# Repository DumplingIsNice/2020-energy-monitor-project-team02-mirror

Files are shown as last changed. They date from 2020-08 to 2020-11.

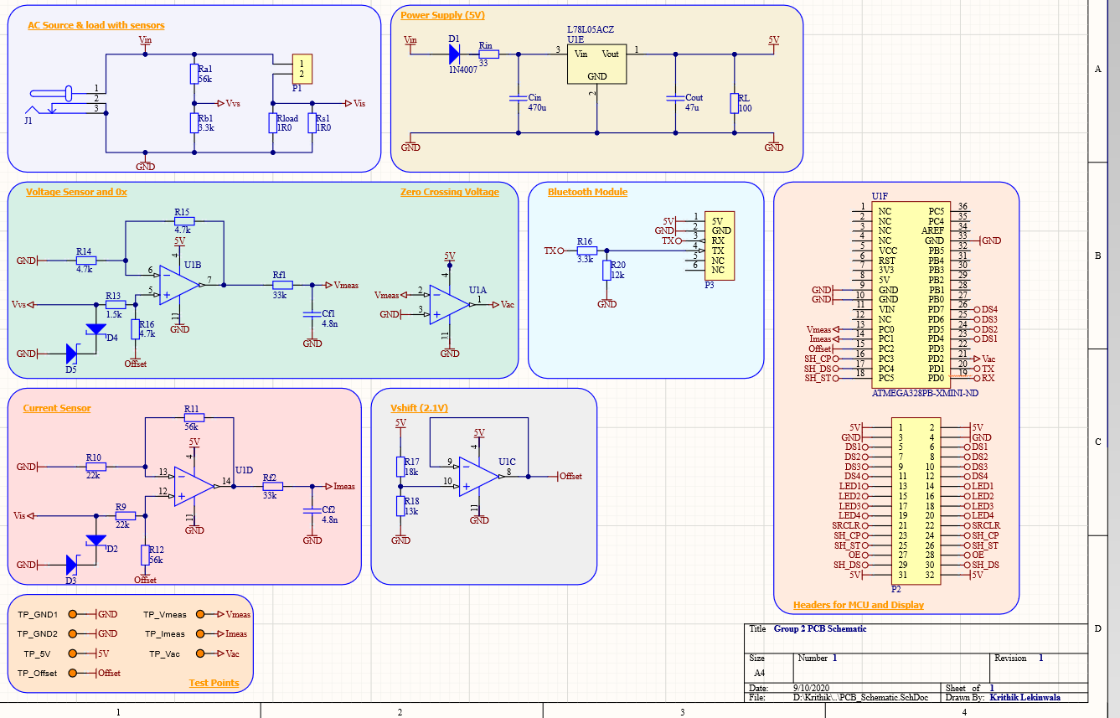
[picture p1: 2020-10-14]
PCB/PCB Schematic/PCBSchem.png

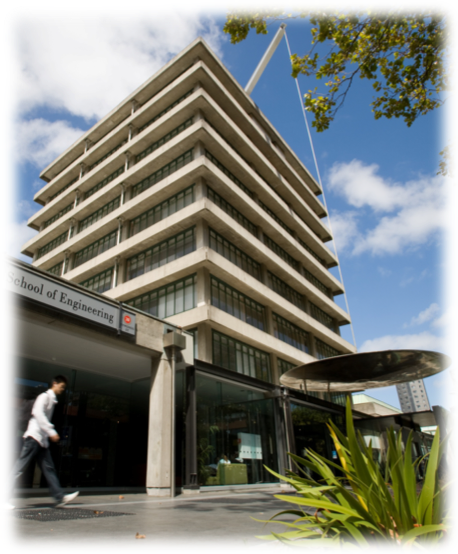
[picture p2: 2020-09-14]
Presentation/img/intro/UoAEng.png

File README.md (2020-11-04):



# Welcome to Team 02 EE209 Project Repository

- **Documentation:** Project brief, specifications and miscellaneous reminders.
- **Firmware:** Program for the ATmega328PB microcontroller.
- **Flowcharts:** Flowcharts of firmware structure.
- **Hardware:** Ltspice model.
- **PCB:** Altium schematic and PCB model.
- **Presentation:** Presentation slides and documents.
- **Proteus:** Proteus model of the energy monitor system.
- **Software:** Python implementation of a web application.

For details regarding each folder, please view the relevant README file.

For more detail regarding the project, please view the [Final Report](./EE209_Report.pdf).

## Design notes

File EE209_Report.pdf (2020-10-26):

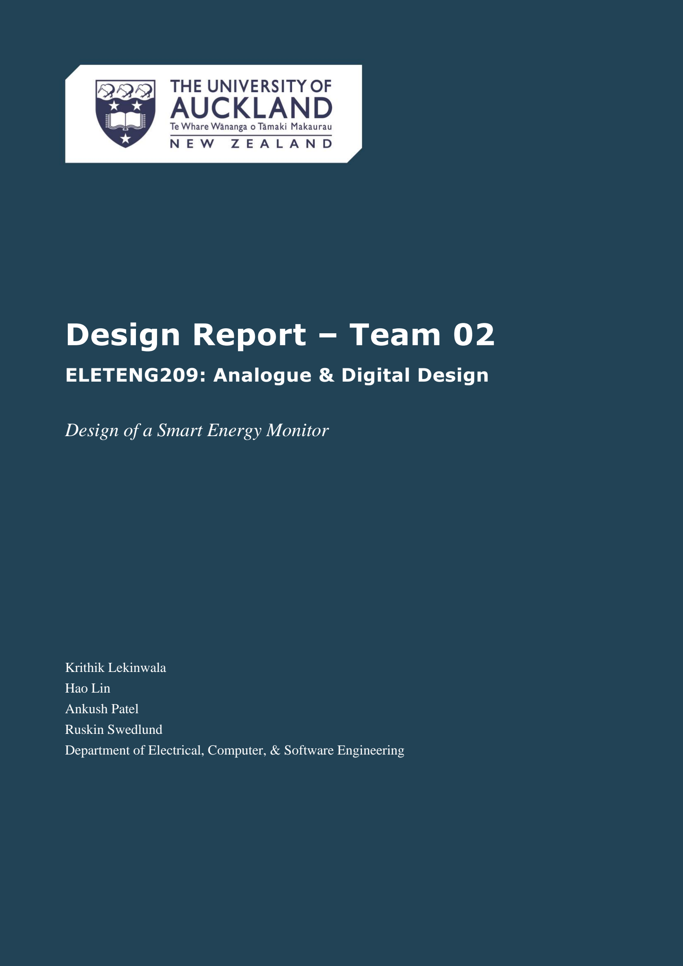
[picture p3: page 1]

# Design Report – Team 02

## ELETENG209: Analogue & Digital Design

## Design of a Smart Energy Monitor

Krithik Lekinwala
Hao Lin
Ankush Patel
Ruskin Swedlund
Department of Electrical, Computer, & Software Engineering

## Abstract

This report describes the design, validation, and operation of a smart energy monitor with the use of an

ATMega328PB capable of measuring the power utilised by an appliance using electrical hardware and

firmware implementations. Some key specifications provided with this Energy Monitor were accuracy,

exporting data to a remote website, and outputting measurements with Bluetooth and wired capability. The

maximum absolute error 5% with a typical error of 0.75%.

## Introduction

The main objective of this project was to gain valuable expertise and experience and to fulfil the course requirements of ELECTENG 209.

This Smart Energy Monitor can measure the power, peak current, RMS voltage, and total energy supplied to a load within specifications. The analogue circuitry measures, filters, and amplifies signals so they are appropriate digital processing. The microcontroller’s firmware samples these signals and interpolates the resulting data to provide an accurate digital representation of the analogue input signals. Results of the completed processing can be sent to a display, smartphones via Bluetooth, and computers using a USB to Serial cable. This overall architecture is summarised in Fig. 1.

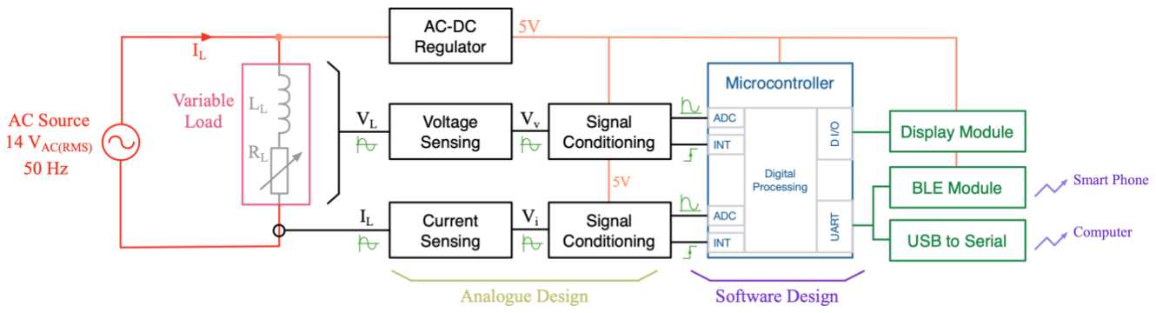
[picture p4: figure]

Fig. 1: A conceptual system diagram [1]

## Literature Research

Table I: A Comparison of existing energy meters

Parameter | Neurio Smart Monitor [2] | Efergy Pro [3]
Operating voltage range | 90 – 130V | 110-300V AC
Accuracy | ±1% of reading | 98%
Power Consumption | < 2 W | 0.2 W
Communication/Display Method | Wi-Fi, Bluetooth, wired | Wi-Fi
Peak Current | --- | 95 mA
Operating Temperature | 0 - 65°C | 0 - 35°C
Measurements | Irms, Vrms, W, X, Wh | W, Irms, Vrms, Energy (Wh)

## Design Specifications

The key differences are in the communication type, operating voltage, and types of measurements. The Neurio monitor measures all the quantities this monitor can, but in addition measures reactive power (X). Efergy Pro only measures Energy. [2] The Nuerio monitor provides Wi-Fi capability in addition to the methods used by the monitor described in this report. [3]
Table II: Design Specifications
Parameter | Configuration
Source Voltage | 14VRMS ± 10%
Source Frequency | 50Hz ± 2%
Load Range | 2.5VA to 7.5VA
Load Power Factor | 0.75 to 0.99
Measurement Accuracy | 5% of full-scale reading
ADC Conversion Rate | 1kHz or slower
LCD Display Information | Voltage, current, power and energy
LCD Display Units | VRMS, Apk, W and Wmin
LCD Scroll Rate | 1s
UART Baud Rate | 9600 Baud
Information Transferred Via UART | Voltage, Current, Power and Energy
PCB Size | 200 mm²
PCB Technology | Double layer with PTH
Device Technology | TH or SMT

## The Analogue Design

## The Schematic

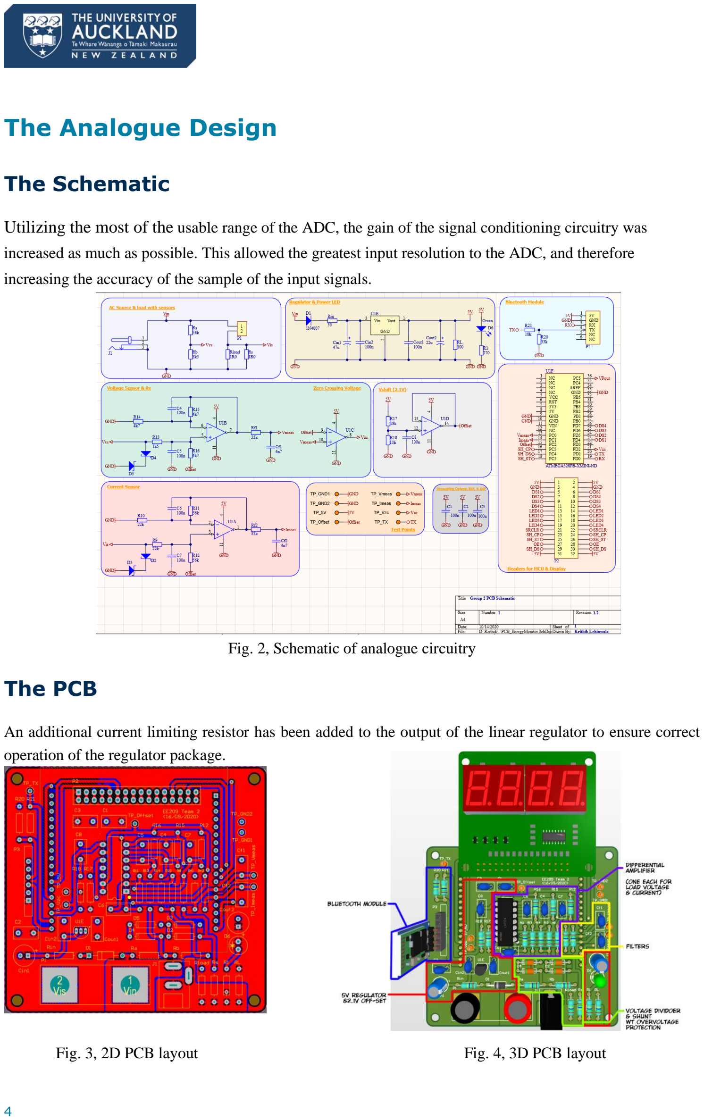
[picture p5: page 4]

Utilizing the most of the usable range of the ADC, the gain of the signal conditioning circuitry was

increased as much as possible. This allowed the greatest input resolution to the ADC, and therefore

increasing the accuracy of the sample of the input signals.

Fig. 2, Schematic of analogue circuitry

## The PCB

An additional current limiting resistor has been added to the output of the linear regulator to ensure correct operation of the regulator package.

Fig. 3, 2D PCB layout | Fig. 4, 3D PCB layout

## Design Validation

For naming convention refer to: https://ee2092020class.github.io/presentations/DigitalL4/presentation.html#5.

Table III: Key design parameters

Parameter | Calculated | Simulated
Gvs | (3300/56000 + 3300) = 0.056
Vvs when VAC is 15.4 Vrms | 0.989 V | 986 mV
Vvs when VAC is 12.6 Vrms | 0.81 V | 805 mV
Gis | 0.56
Vis when IAC is 0.60 Arms | 0.47 V | 0.446 V
Vis when IAC is 0.16 Arms | 0.127 V | 0.125 V
Gvo | (4700/4700) = 1
Vvo when VAC is 15.4 Vrms | 3.09 V | 3.09 V
Vvo when VAC is 12.6 Vrms | 2.91 V | 2.91 V
Gio | (56000/22000) = 2.55
Vio when IAC is 0.60 Arms | 3.1 V | 3.08 V
Vio when IAC is 0.16 Arms | 2.37 V | 2.37 V
Gvf | 1
Vvf when VAC is 15.4 Vrms | 3.32 V | 3.29 V
Vvf when VAC is 12.6 Vrms | 3.1 V | 3.08 V
Gif | 1
Vif when IAC is 0.60 Arms | 3.31 V | 3.29 V
Vif when IAC is 0.16 Arms | 2.42 V | 2.43 V
ΔVin of 5V regulator | 2.13 V | 1.56 V
ΔV5V of 5V regulator | 0 V | 0 V

## The Embedded Software Design

## Flowchart

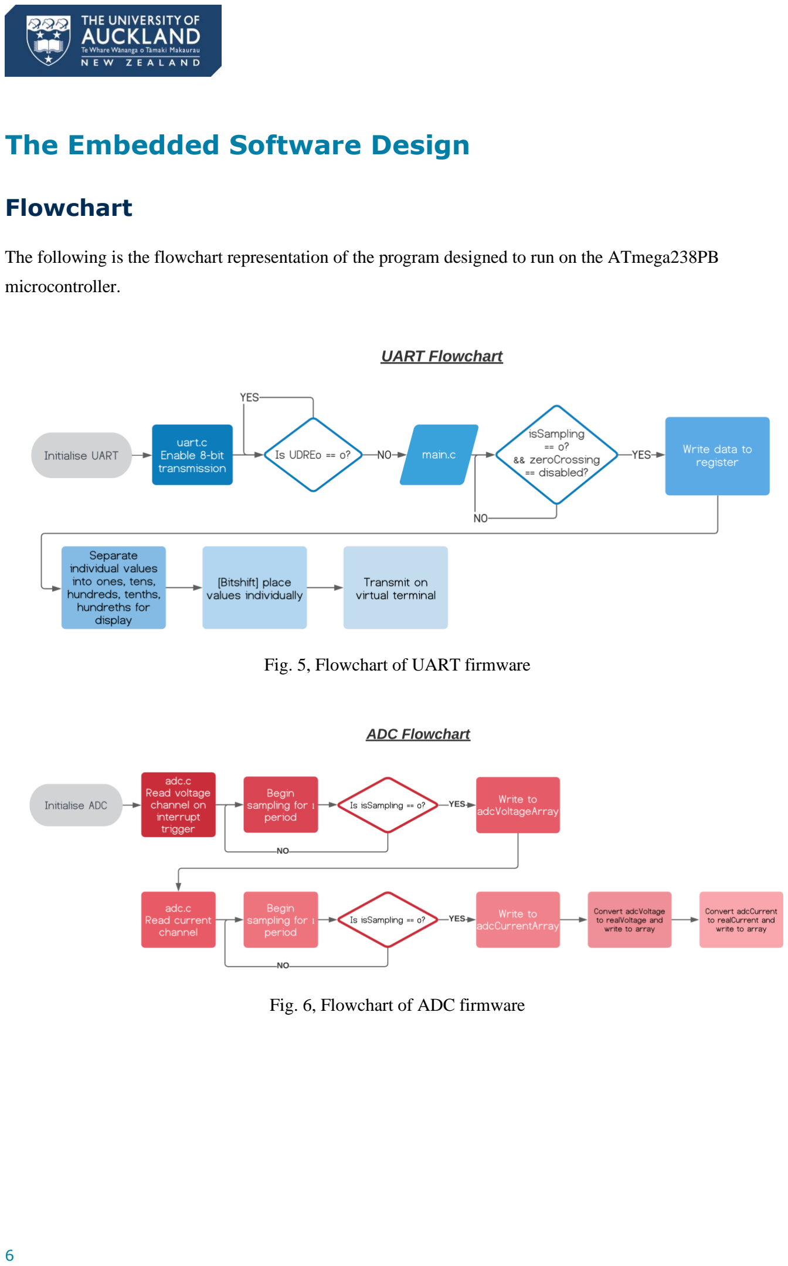
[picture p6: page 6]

The following is the flowchart representation of the program designed to run on the ATmega238PB

microcontroller.

Fig. 5, Flowchart of UART firmware

Fig. 6, Flowchart of ADC firmware

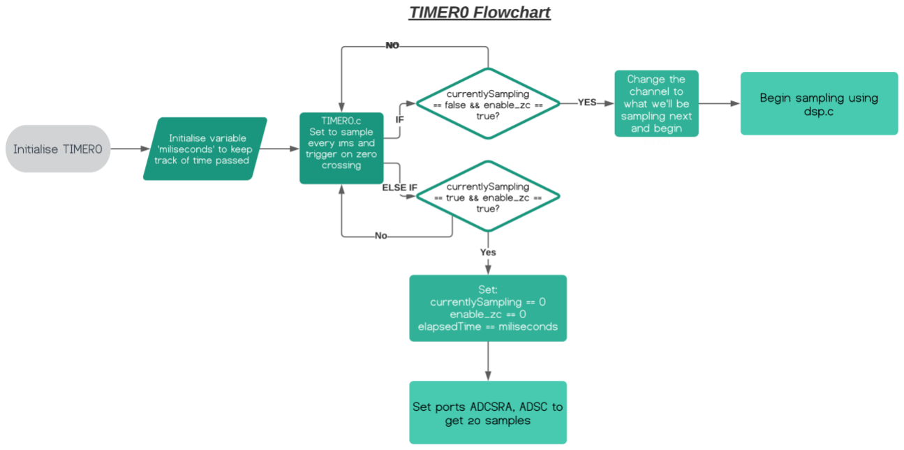
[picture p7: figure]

Fig. 6, Flowchart of TIMER0 firmware

In processing the samples, cubic interpolation and Simpsons rule was used to integrate points for power and RMS voltage. The cubic interpolation used was specifically chosen as the most suitable numerical integration method to accurately predict the peak values of imperfect sinusoidal waves.

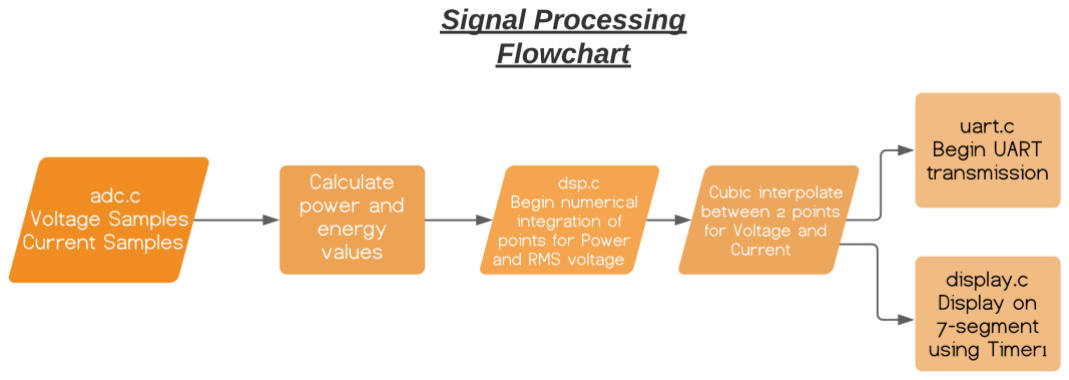
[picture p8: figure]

Fig. 7, Flowchart of digital signal processing firmware

## Custom Print Function

A custom print function was implemented for use by the UART peripheral to reduce clutter, memory used, and to increase functionality. This function can transmit directly to the terminal by using:

print(“xyz: %d %f”, current, voltage)

## Smart Energy Challenge

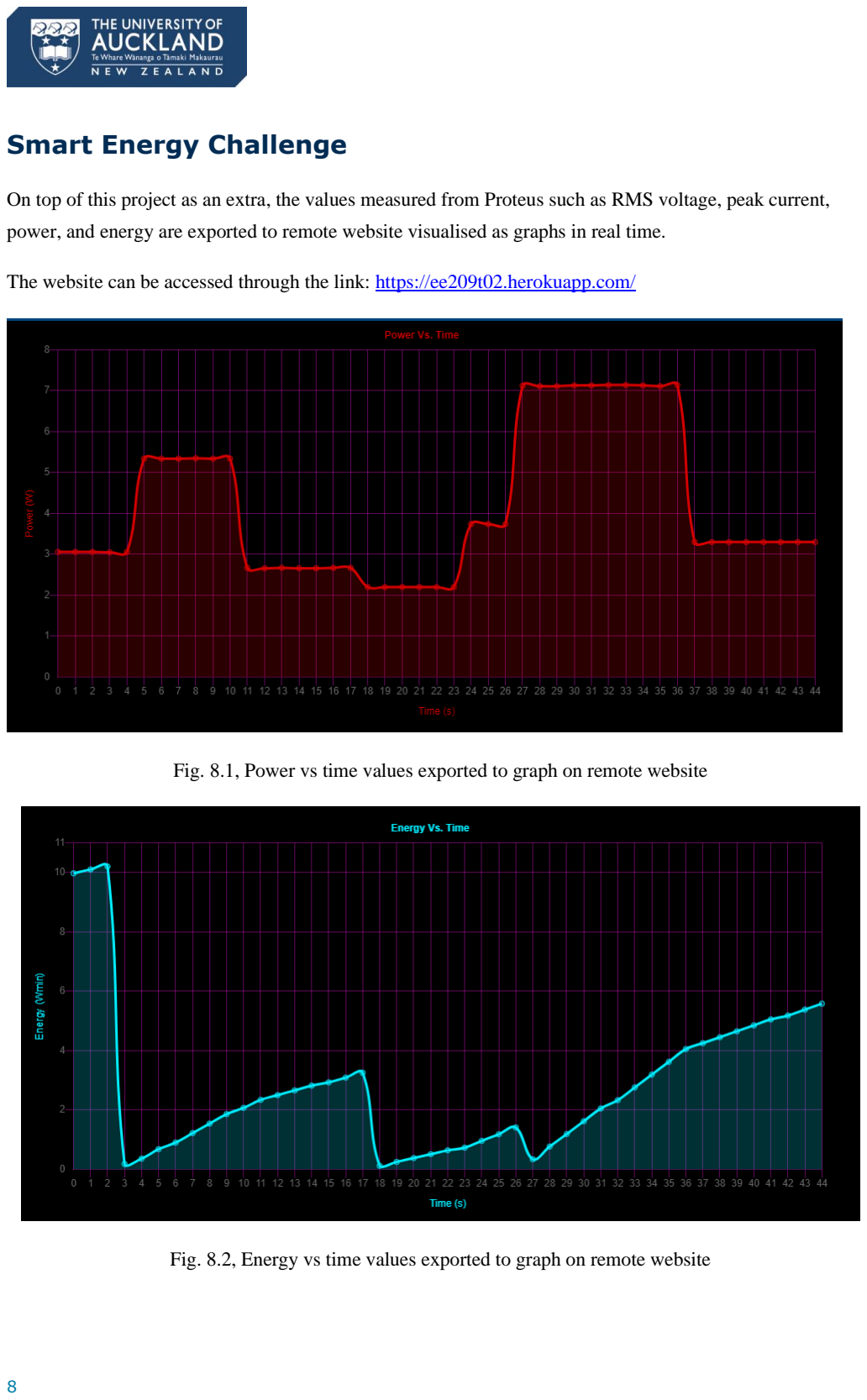
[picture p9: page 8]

On top of this project as an extra, the values measured from Proteus such as RMS voltage, peak current,

power, and energy are exported to remote website visualised as graphs in real time.

The website can be accessed through the link: https://ee209t02.herokuapp.com/

Fig. 8.1, Power vs time values exported to graph on remote website

Fig. 8.2, Energy vs time values exported to graph on remote website

## Peripheral Configurations

Table IV: UART configuration

Parameter | Configuration
Number of data bits | 8
Number of stop bits | 1
Baud rate | 9600
Parity mode | None
Transmission mode | Simplex (transmit)
Transmit mode | Polling (UDRE0)
Transmit voltage | 5 V

Table V: ADC configuration

Parameter | Configuration
Prescaler | 4 (sim), 128 (hardware)
Timer0 ADC mode | CTC A auto trigger
ADC interrupt time | 1ms
Voltage reading | ADC channel 0
Current reading | ADC channel 1
OCR0A | 99 (sim), 124 (hardware)

Table VI: Display Configuration

Parameter | Configuration
7-Segment pin operation | Common Cathode
Units display | Ds4
Clock Pulse bit | SH_CP
Timer2 interrupt time | 1ms
Timer2 OCR2A | 99 (sim), 124 (hardware)
Timer2 display update interval | 10ms
4 Display operation | Shift Register

Table VII: I/O pins

Parameter | Configuration
7 Seg Display Output | Ds1, Ds2, Ds3, Ds4 (PD4, PD5, PD6, PD7)
Reading Shift Register | SH_DS (PC4)
Toggle shift register | SH_ST (PC5)
LED toggle for testing operation | LED (PB5)

## Design Validation

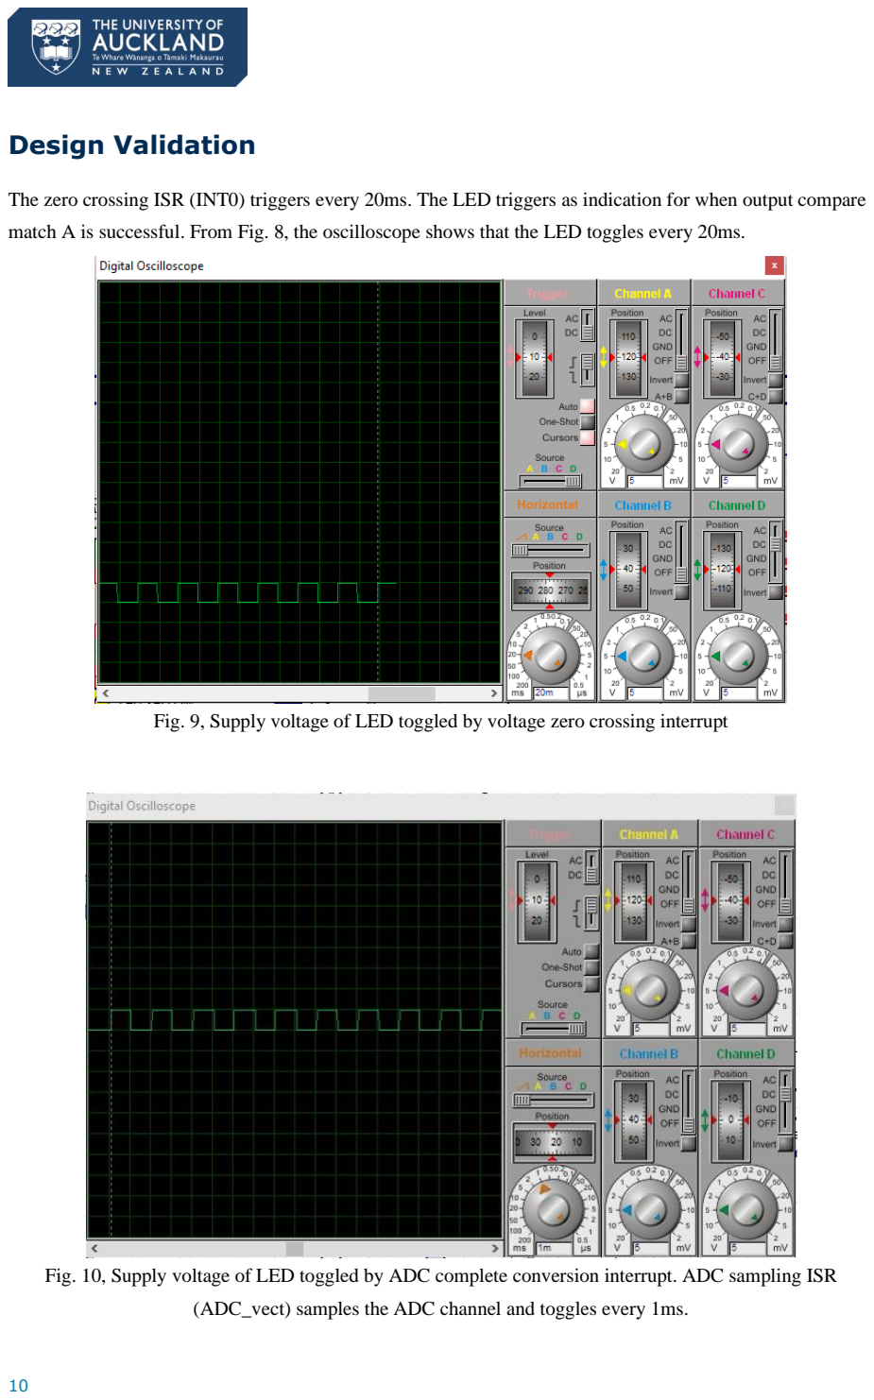
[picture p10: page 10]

The zero crossing ISR (INT0) triggers every 20ms. The LED triggers as indication for when output compare

match A is successful. From Fig. 8, the oscilloscope shows that the LED toggles every 20ms.

Fig. 9, Supply voltage of LED toggled by voltage zero crossing interrupt

Fig. 10, Supply voltage of LED toggled by ADC complete conversion interrupt. ADC sampling ISR

(ADC_vect) samples the ADC channel and toggles every 1ms.

Timer2 triggers approximately every 10.8ms. Timer2 is used to drive the refresh rate of the seven-segment

display. Shown in Fig 10, the shift register clock pulse control signal (SH_CP, in yellow) is used to move

data into the shift register.

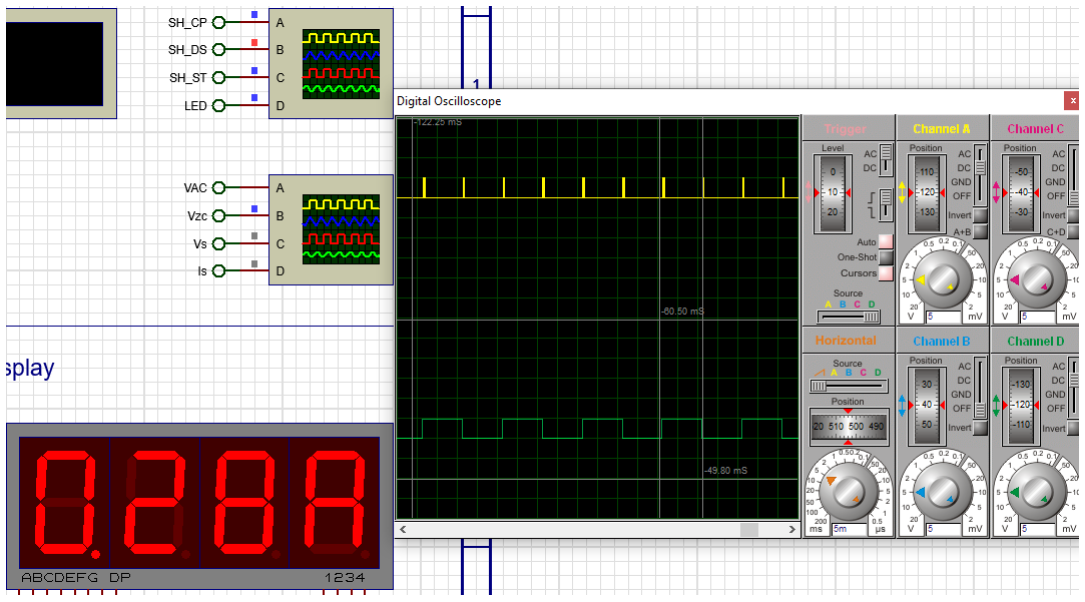
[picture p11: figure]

Fig. 11, Voltage supply to LED toggled by TIMER2 interrupt in green, shift register clock pulse in yellow

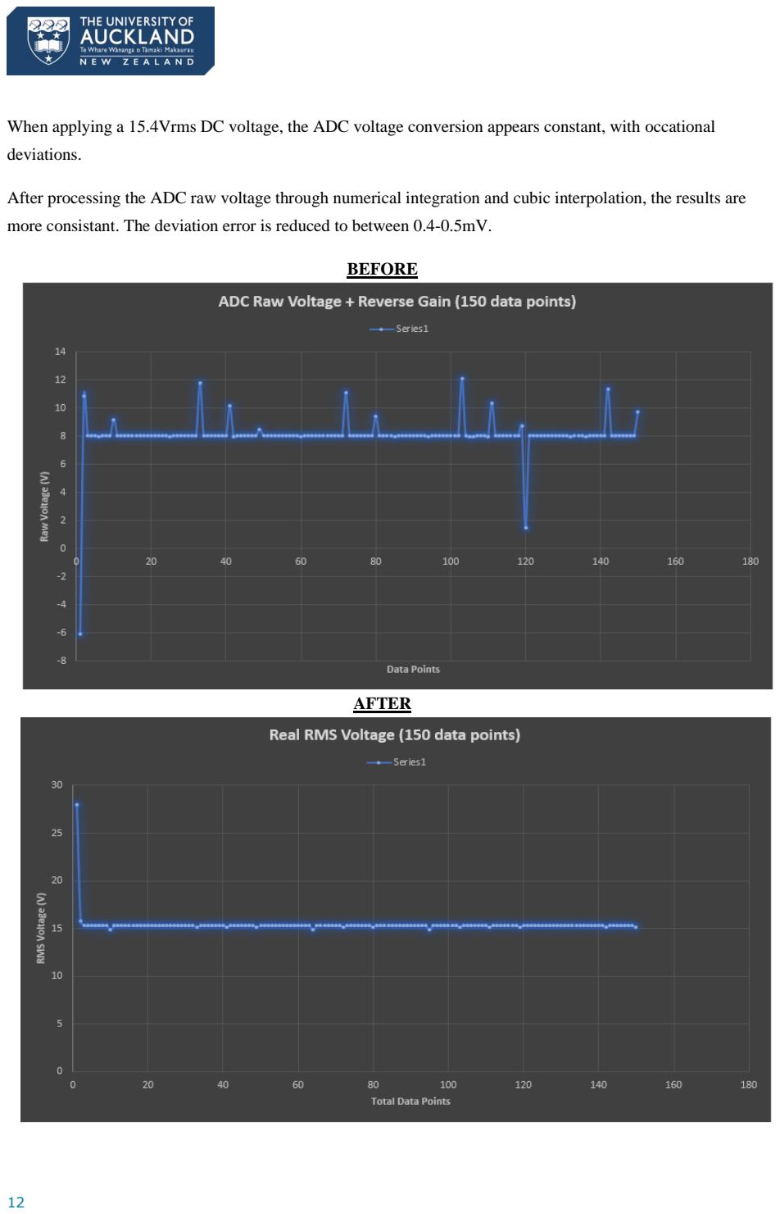
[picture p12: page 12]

When applying a 15.4Vrms DC voltage, the ADC voltage conversion appears constant, with occational

deviations.

After processing the ADC raw voltage through numerical integration and cubic interpolation, the results are

more consistant. The deviation error is reduced to between 0.4-0.5mV.

BEFORE

AFTER

## Performance of the Energy Monitor

## Design Validation

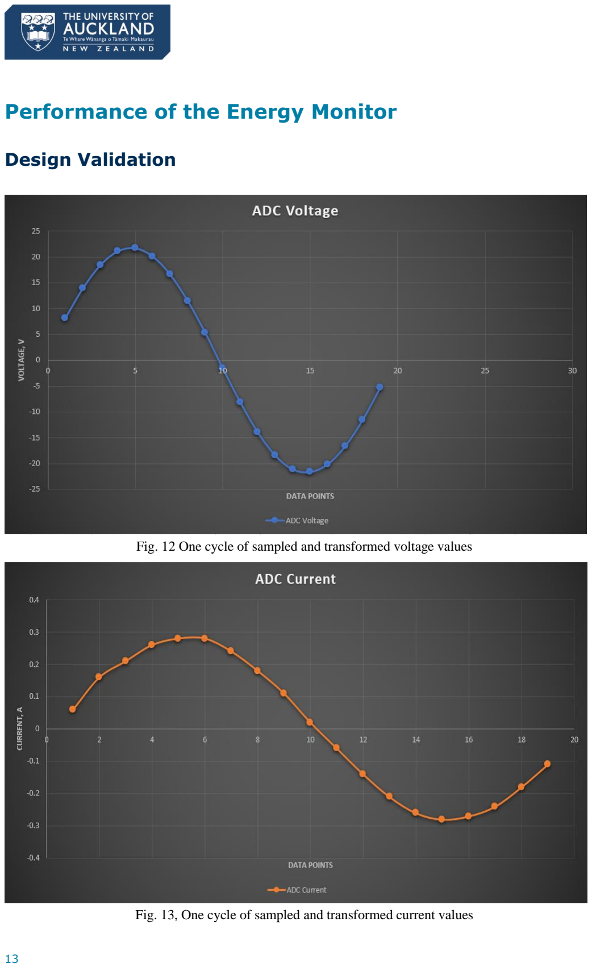
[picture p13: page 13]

Fig. 12 One cycle of sampled and transformed voltage values

Fig. 13, One cycle of sampled and transformed current values

## The Accuracy

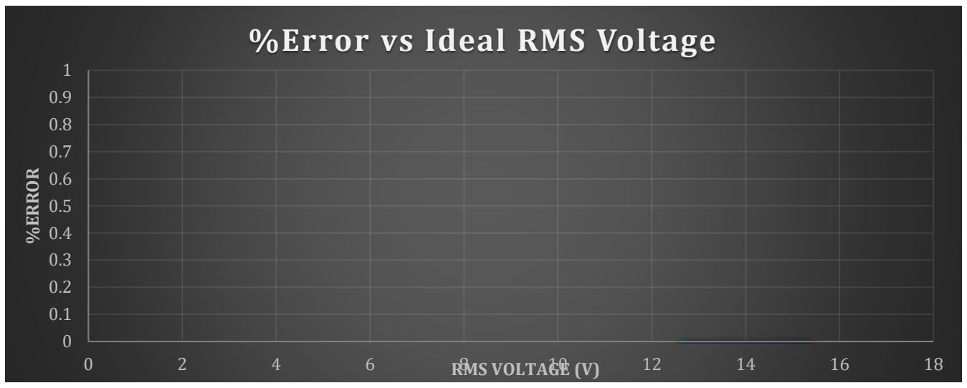
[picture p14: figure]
%ERROR; RMS VOLTAGE (V); %Error vs Ideal RMS Voltage

Fig. 14, Ideal Peak Current vs Error graph (most points not visible due to error being 0)

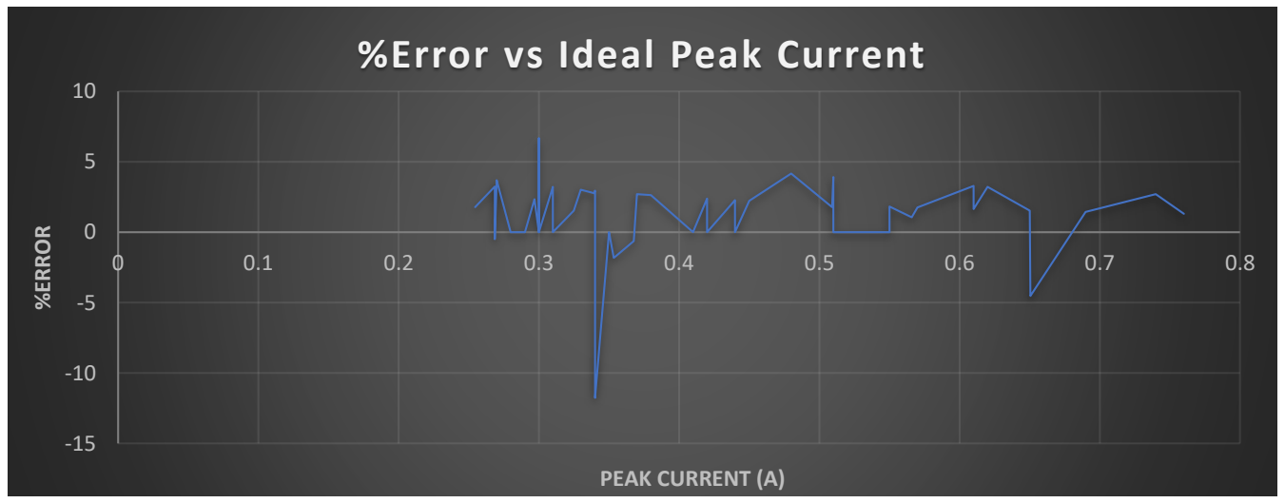
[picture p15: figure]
%ERROR; PEAK CURRENT (A); %Error vs Ideal Peak Current

Fig. 15, Ideal RMS Voltage vs Error graph

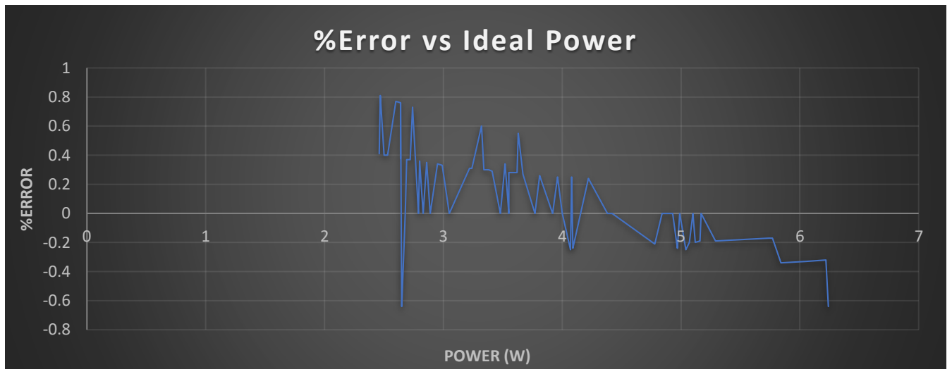
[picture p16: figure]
%ERROR; POWER (W); %Error vs Ideal Power

Fig. 16, Ideal Average Power vs Error graph

## Conclusions

In conclusion to this Energy Monitor Project, this report discusses how the Energy Monitor operates in terms

of its firmware and hardware, accuracy, workability, and comparisons to commercial grade products. The

typical accuracy reached using numerical and cubic interpolation techniques was approximately 0.75%. The

aim of this report was to give the reader some insight on an Energy Monitor and how it can be used in a real-

world application example.

## References

[1] D. J. Thrimawithana, Class Lecture, Topic: "Analogue & Embedded Software Design: An Introduction to the Course" ELECTENG 209, Department of Electrical, Computer, and Software Engineering, The University of Auckland, Auckland, October 2020.
[2] Efergy Pro Energy Monitor, https://efergy.com/efergy-pro-specs/#
[3] Neurio Home Energy Monitor Datasheet, https://www.neur.io/wp-content/uploads/Neurio_Home_Energy_Monitoring_Kit_SpecSheet.pdf (https://www.neur.io/wp-content/uploads/Neurio_Home_Energy_Monitoring_Kit_SpecSheet.pdf)

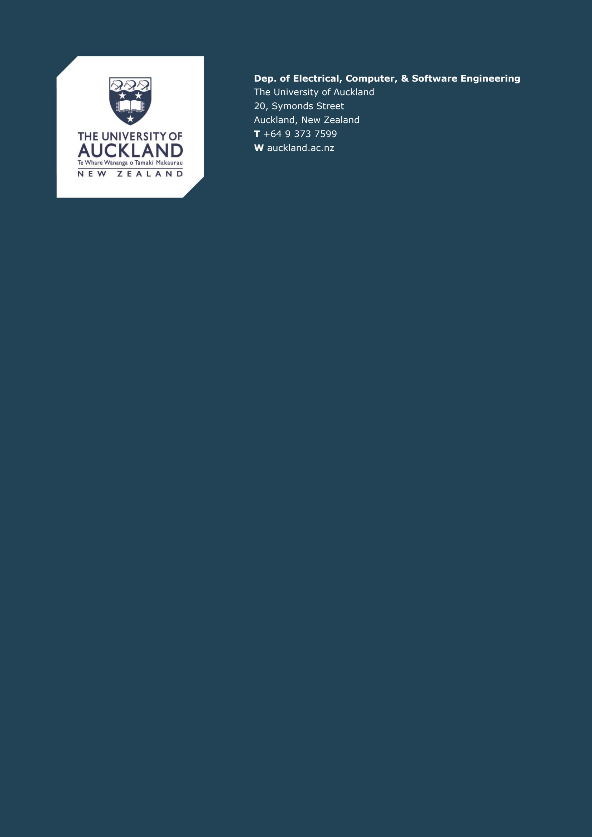
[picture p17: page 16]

Dep. of Electrical, Computer, & Software Engineering The University of Auckland
20, Symonds Street
Auckland, New Zealand
T +64 9 373 7599
W auckland.ac.nz

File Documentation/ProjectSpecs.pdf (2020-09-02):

## ENGGEN209 - Team 2 - Project Specifications:

Overview Of System To Impliment:

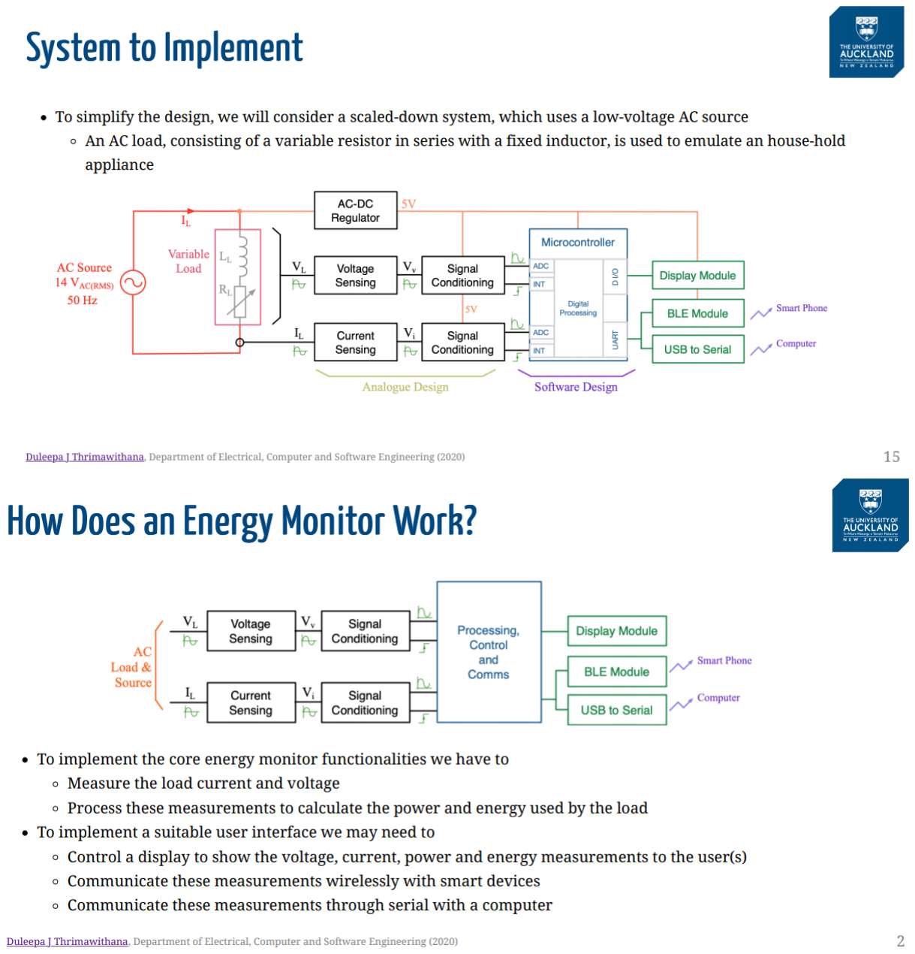
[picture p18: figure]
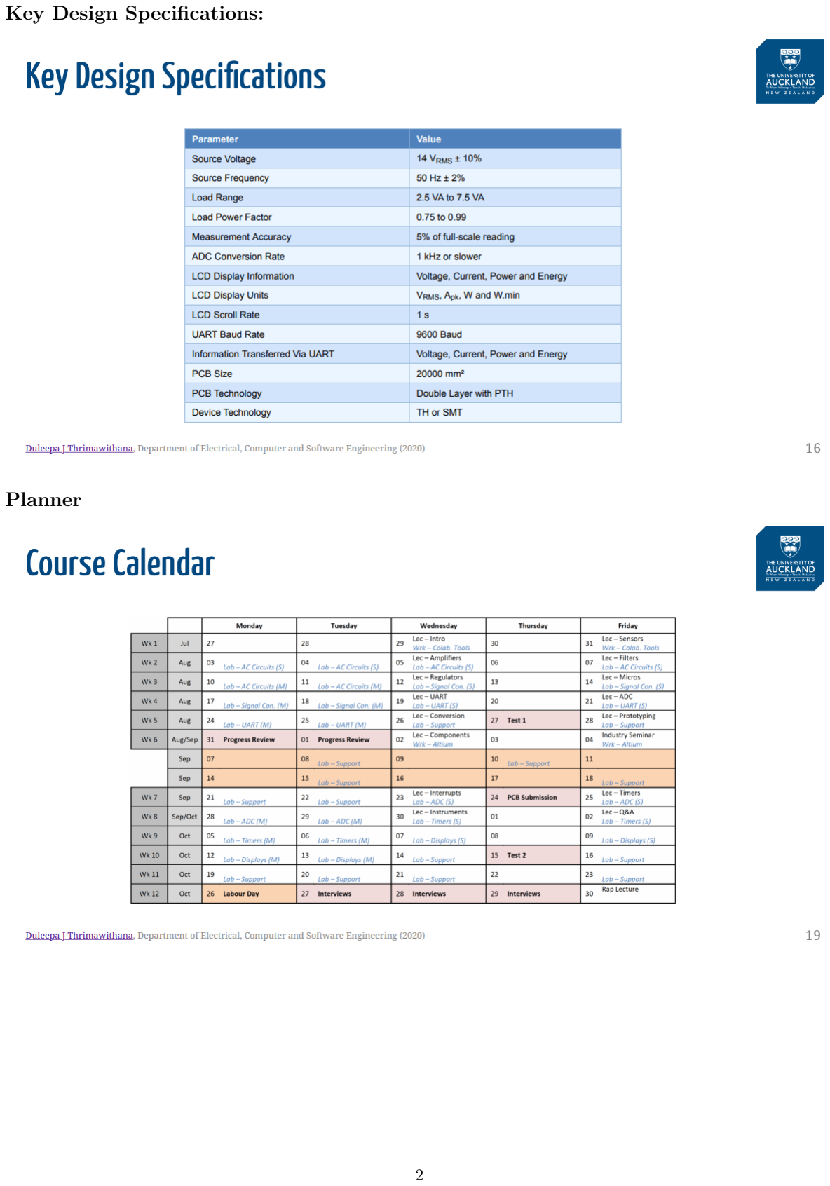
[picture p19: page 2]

Key Design Specifications:

Planner

Circuitry to sense the voltage and current supplied to the load:

- Signal conditioning circuitry to amplify and filter the sensed voltage and current signals.
- A software-based digital processing system, which uses an ATmega328P microcontroller, to convert the analogue signals provided by the signal conditioning circuit to digital form and calculate the voltage, current, power and energy.
- AC to DC regulator circuitry to generate a 5 V DC supply for the analogue (and digital) circuitry employed in the energy monitor.
- A 7-segment LCD display module, which is connected to the microcontroller via a shift-register, to show the calculated information.
- A Bluetooth LE module, which is connected to the microcontroller via Universal Asynchronous Receiver/Transmitter (UART), to communicate information with a smart device like a phone.
- A USB interface with serial emulation, which is connected to the microcontroller via UART, to communicate information with a laptop/PC.

Provided Items

- The source configuration circuit.
- An Xplained Mini 328PB microcontroller module with headers providing easy access to the ports
- An HM-10 Bluetooth LE module which contains a CC2540 system-on-chip (SoC) and associated circuitry needed to interface directly with the UART port of the microcontroller
- A 4-digit seven-segment LCD display module which contains a 74HC595 shift-register and the logic circuitry required to interface with digital IO pins of the microcontroller.

Bluetooth Module UART Specs:

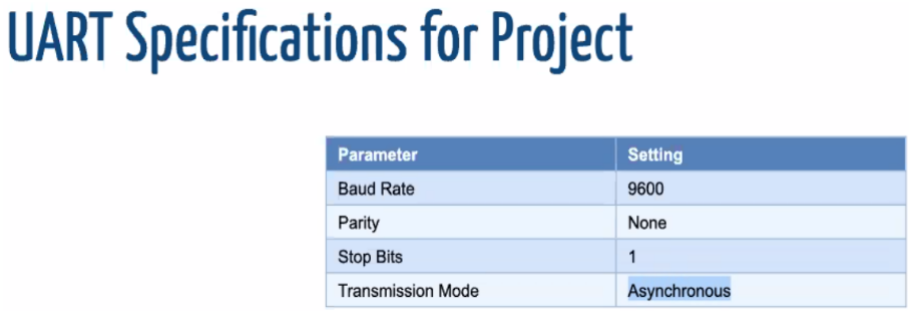
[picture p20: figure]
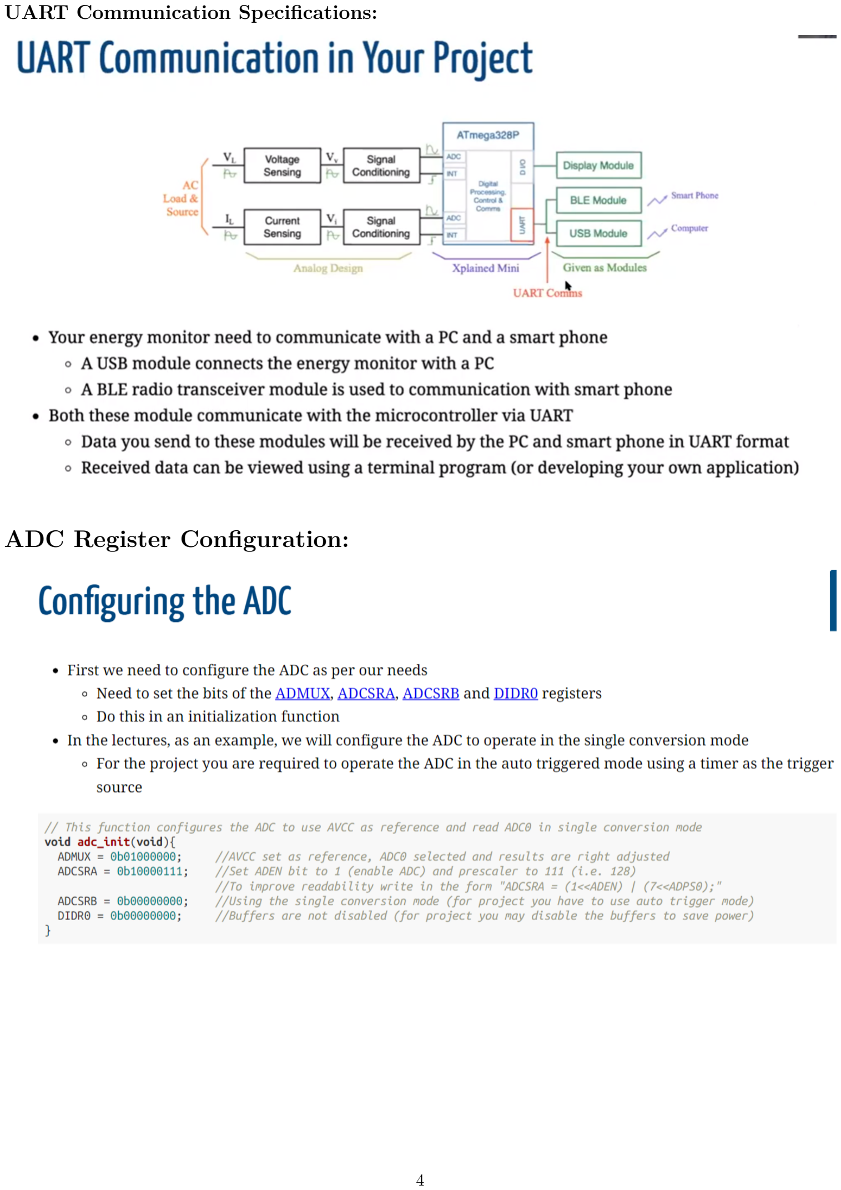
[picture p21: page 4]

UART Communication Specifications:

## ADC Register Configuration:

## PCB Design Considerations:

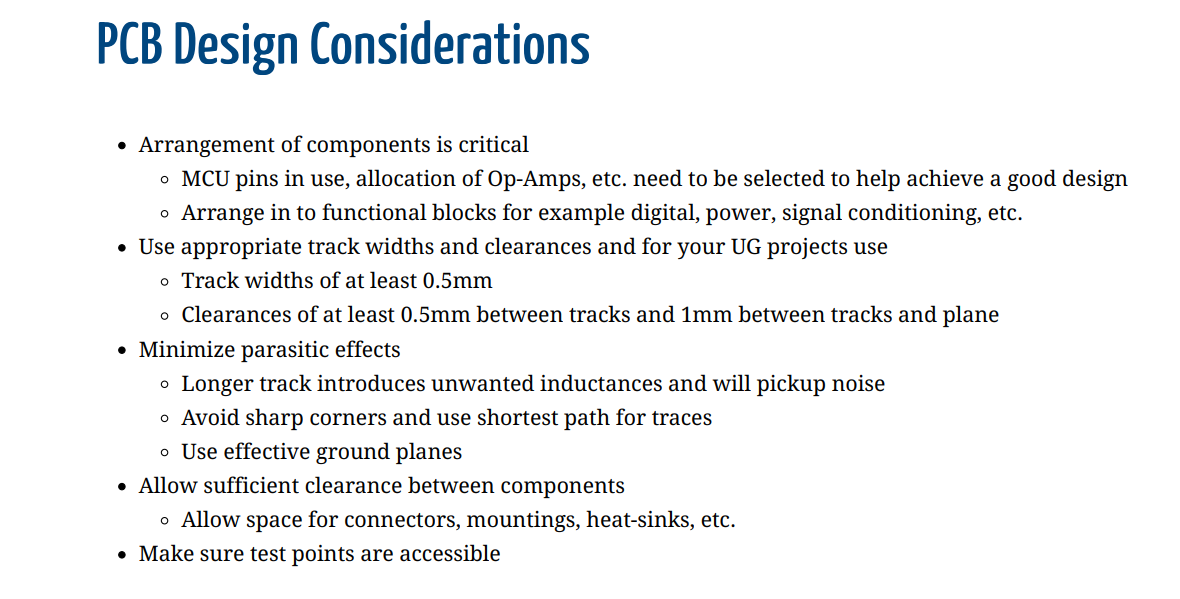
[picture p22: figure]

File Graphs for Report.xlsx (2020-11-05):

Voltage | Current
8.15 | 0.06
13.9 | 0.16
18.4 | 0.21
21.1 | 0.26
21.7 | 0.28
20.1 | 0.28
16.6 | 0.24
11.5 | 0.18
5.34 | 0.11
-1.49 | 0.02
-8.07 | -0.06
-13.9 | -0.14
-18.4 | -0.21
-21.1 | -0.26
-21.6 | -0.28
-20.1 | -0.27
-16.6 | -0.24
-11.5 | -0.18
-5.27 | -0.11
15.4 |  | Error | 0.2
RMS Voltage | Ideal RMS Voltage |  | Peak Current | Ideal Peak Current x (√2) | Error | Average Power | Ideal Average Power | Error | Ideal Vrms | %Error | Ideal Cpk |  | %Error | Ideal P |  | %Error
15.8 | 15.4 | 0.4 | 0.28 | 0.2828427125 | 0.002842712475 | 3.01 | 3.08 | 0.07 | 12.6 | 0 | 0.254558 | 1.790554608 | 1.79 | 2.46 | 0.406504065 | 0.41
15.3 | 15.4 | 0.1 | 0.28 | 0.2828427125 | 0.002842712475 | 3.06 | 3.08 | 0.02 | 12.6 | 0 | 0.2687 | 3.237811686 | 3.24 | 2.47 | 0.8097165992 | 0.81
15.3 | 15.4 | 0.1 | 0.28 | 0.2828427125 | 0.002842712475 | 3.05 | 3.08 | 0.03 | 12.7 | 0 | 0.2687 | -0.4838109416 | -0.48 | 2.5 | 0.4 | 0.4
15.3 | 15.4 | 0.1 | 0.28 | 0.2828427125 | 0.002842712475 | 3.05 | 3.08 | 0.03 | 12.8 | 0 | 0.27 | 3.703703704 | 3.7 | 2.53 | 0.395256917 | 0.4
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

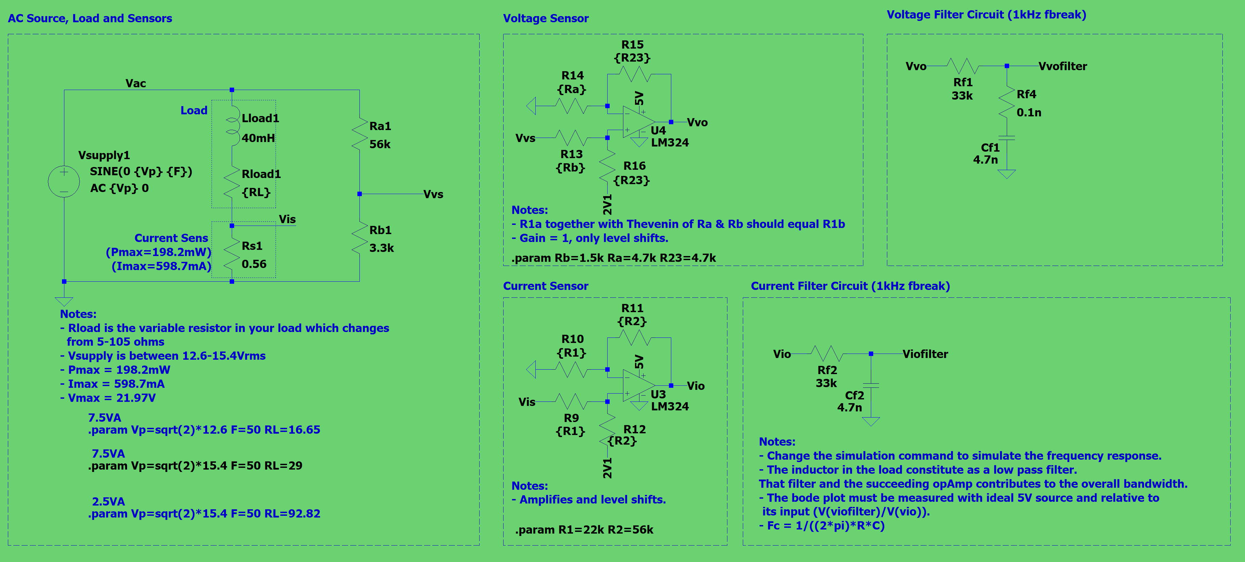
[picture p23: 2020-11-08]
Presentation/img/Ltspice Schematic.png

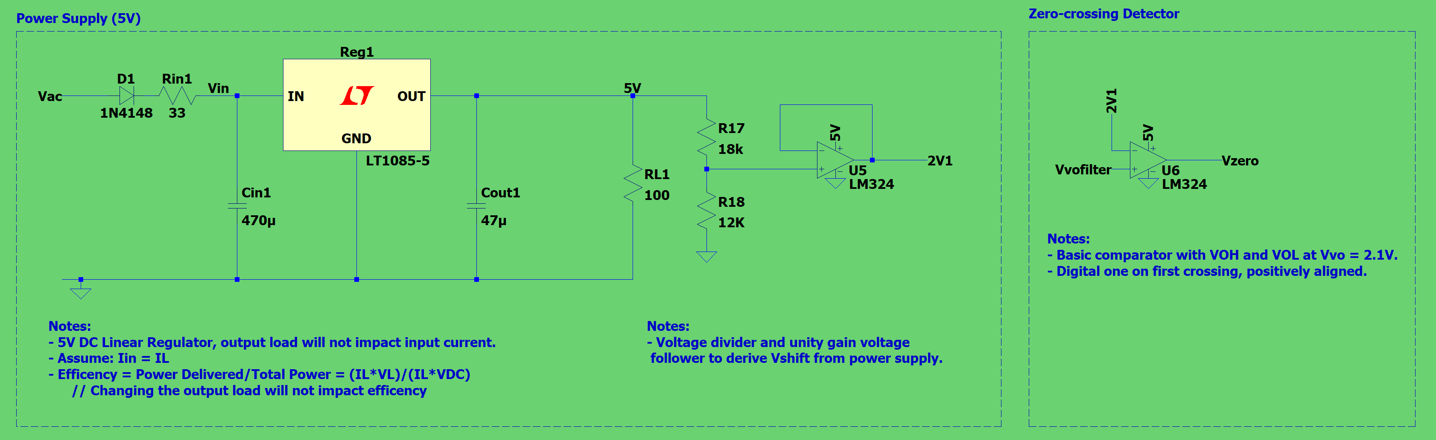
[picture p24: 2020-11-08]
Presentation/img/Ltspice Schematic2.png

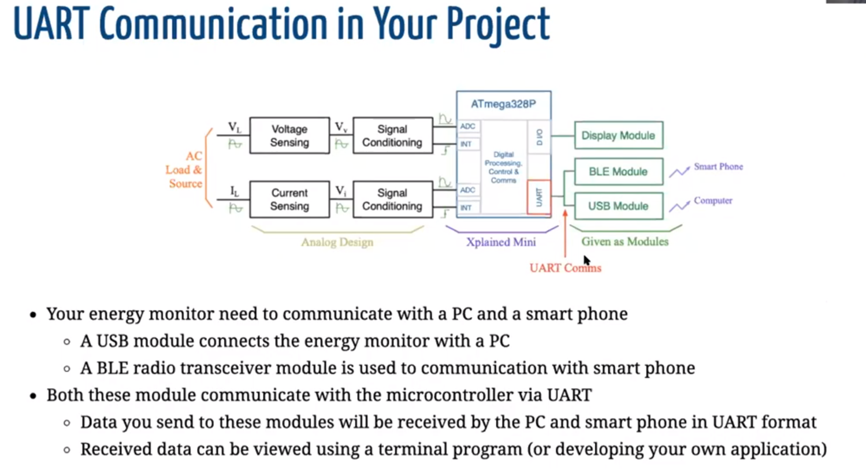
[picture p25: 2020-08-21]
Documentation/src/project_specs/UARTCommunication.png

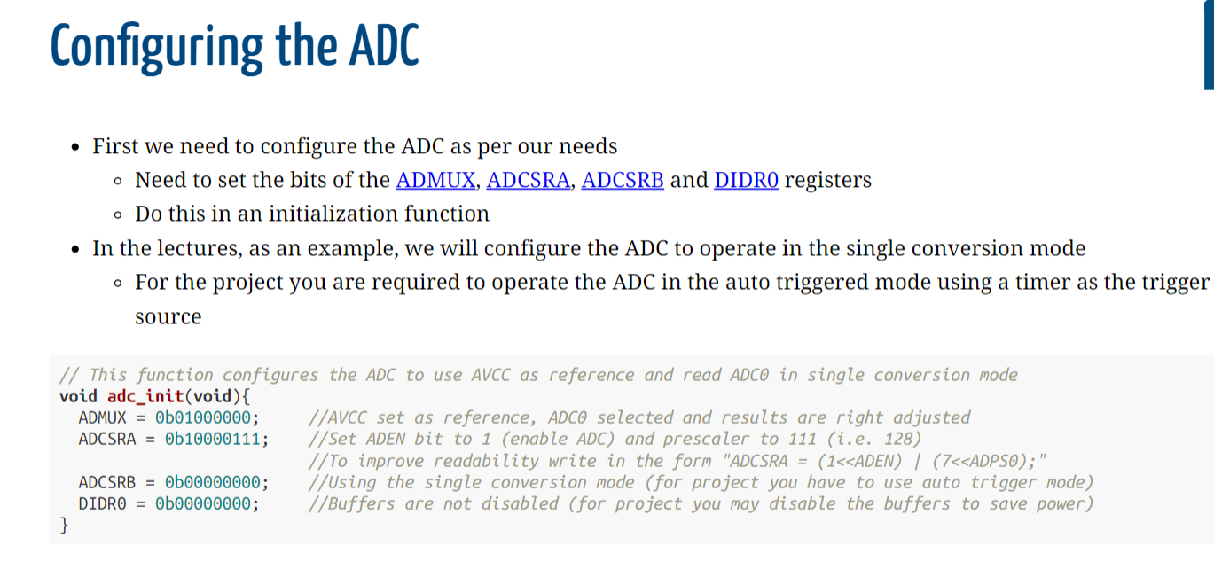
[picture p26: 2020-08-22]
Documentation/src/project_specs/ADCConfig.png

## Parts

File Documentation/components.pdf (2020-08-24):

# ELECTENG209 Team 02: Project Component Values

### Ankush Patel, Daniel Lin, Krithik Lekinwala, Rukin Swedlund

13/08/2020

1

## Contents

1 Introduction | 3
2 Voltage & Current Sensors | 4
3 Measurement Conditioning | 6
4 Filters | 8
5 Zero Crossing Detection | 8
6 The E-12 Series: | 9

2

## 1 Introduction

This document details the circuits and component values we will use to build our project. The structure and order of the component values and circuits described follow the order of the Labs.
The basic structure of components is as follows:

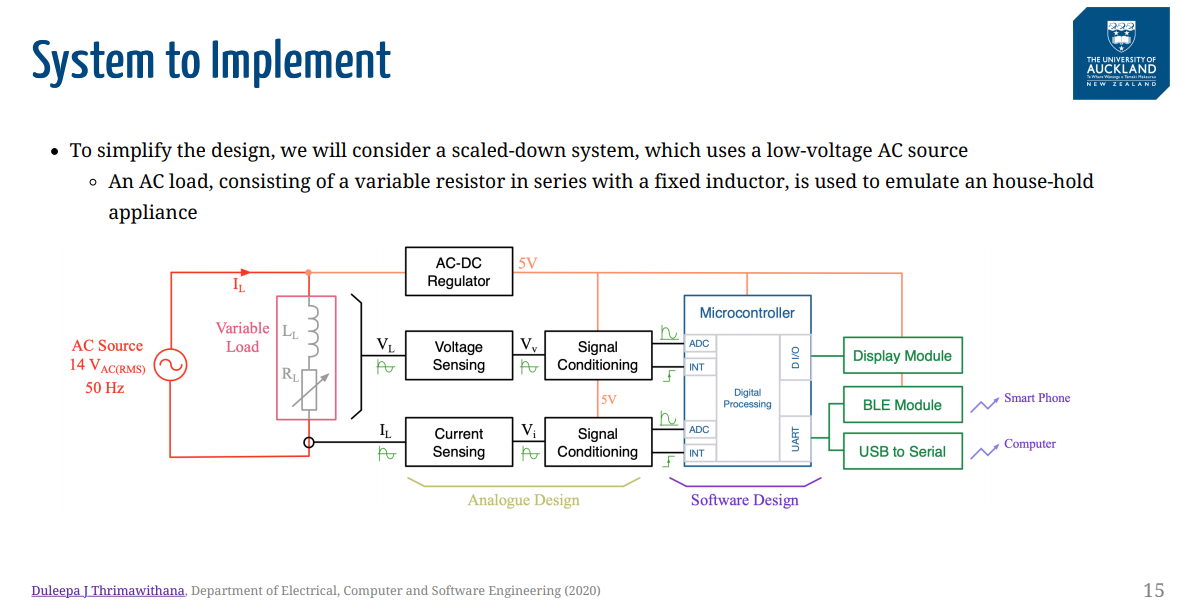
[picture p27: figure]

All (fixed) component values are based on the The E-12 Series

3

## 2 Voltage & Current Sensors

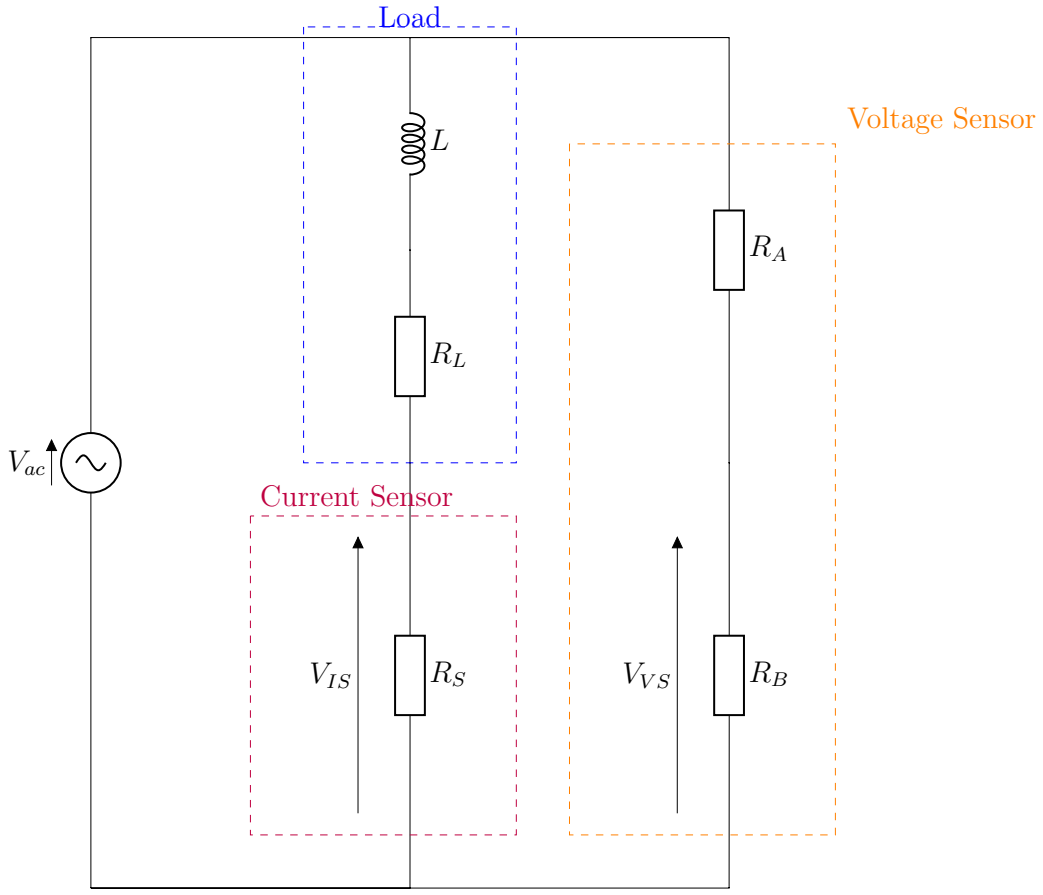
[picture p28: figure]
Vac; VIS; Load; Current Sensor; Voltage Sensor

RS is the Shunt Resistor that we use to measure the current drawn through the load.
VIS is the voltage dropped across the shunt resistor (RS). This drop in voltage is proportional to the current through the shunt resistor (and therefore proportional to the current through the load).

The nominated value of RS is RS = 0.56 Ω.

RA and RB are the two Voltage Dividers that make up the voltage sensor. The Voltage sensors output is taken to be the voltage across RB (VV S).

The nominated values for RA and RB are: RA = 82 kΩ and RB = 3.8 kΩ.

4

The following is a table of values to use for testing the limits of the sensors:

Source VAC | VAC(RMS) | RL
7.5 VA | 12.6 V | 16.65 Ω
7.5 VA | 15.4 V | 29.00 Ω
2.5 VA | 15.4 V | 92.82 Ω

5

## 3 Measurement Conditioning

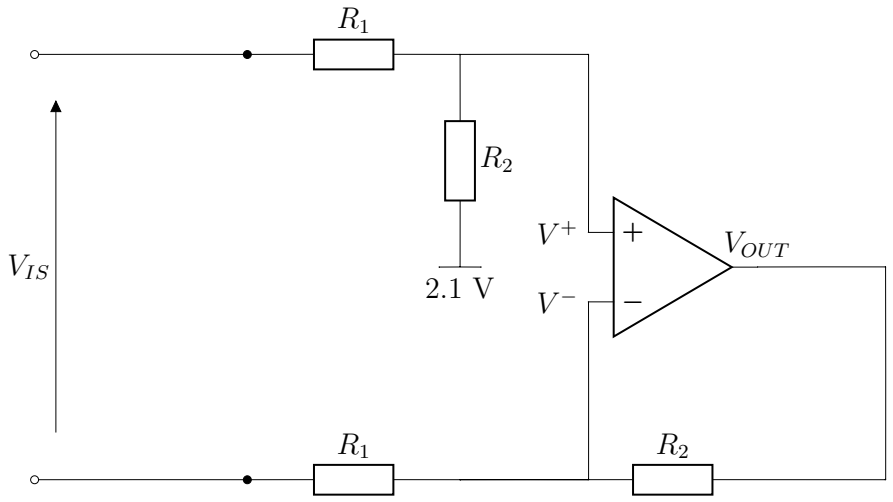
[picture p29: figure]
VIS; VOUT

Figure 1: Current Signal Conditioning Circuit

The the four resistors of value R1 and R2 control the gain and offset applied by the Operational Amplifier to the input signal VIS.

The value of R1 and R2 is: R1 = 3.9 kΩ and R2 = 82 kΩ.

6

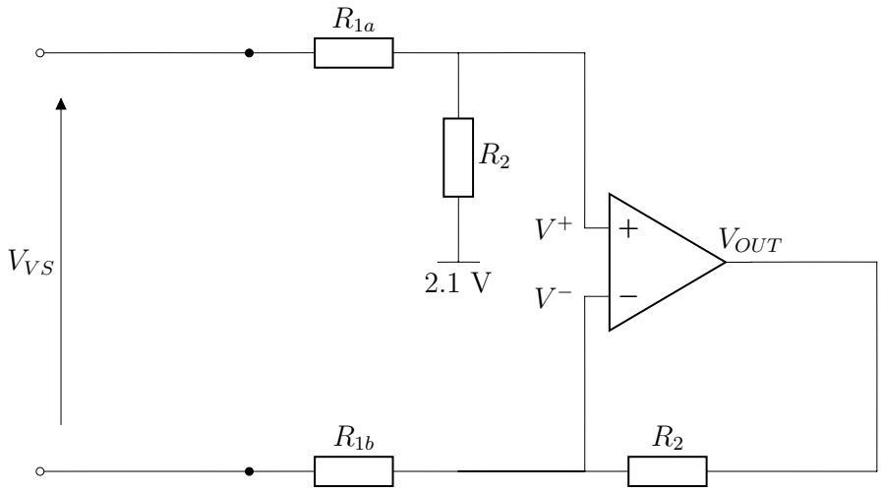
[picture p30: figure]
VOUT

Figure 2: Voltage Signal Conditioning Circuit

The four resistors of value R1a, R1b and R2 control the gain and offset applied by the Operational Amplifier to the input signal VV S.

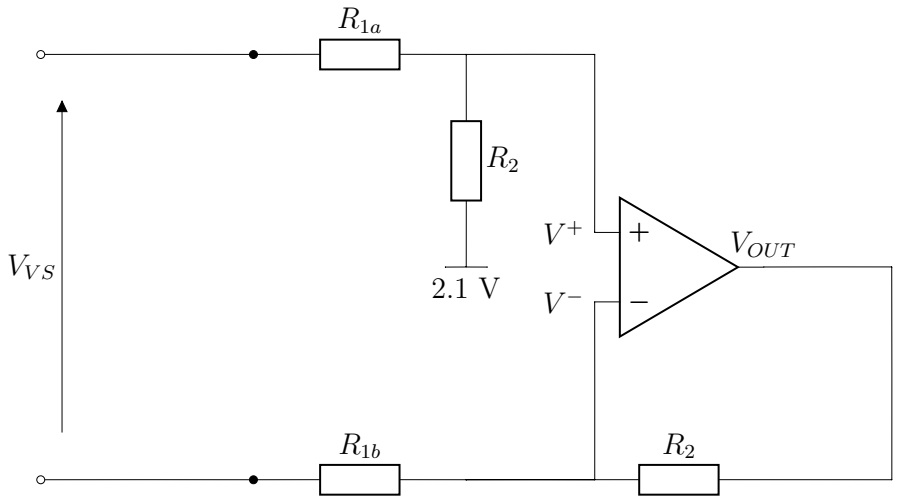
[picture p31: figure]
VOUT

Figure 3: Voltage Signal Conditioning Circuit

The value of R1a, R1b and R2 is: R1a = 1.0 kΩ, R1b = 4.7 kΩ and R2 = 4.7 kΩ.

7

## 4 Filters

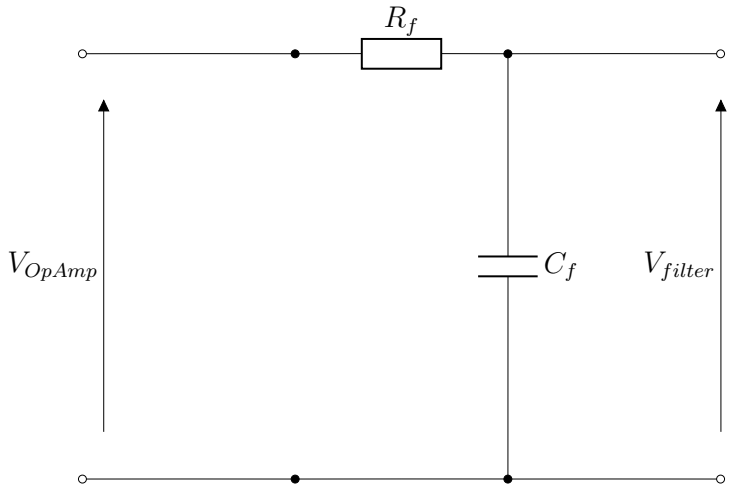
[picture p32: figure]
VOpAmp; Vf ilter

The Resistor and Capacitor create a filter that has a breakpoint frequency of 100 kHz.

The value of Rf and Cf is: Rf = 33 kΩ and Cf = 4.8 nF.

## 5 Zero Crossing Detection

−

VV O | +
2.1 V | VZERO

Figure 4: Voltage Signal Conditioning Circuit

2.1 V is a voltage source, VV O is the conditioned voltage signal.

8

## 6 The E-12 Series:

1.0 Ω 1.2 Ω 1.5 Ω 1.8 Ω 2.2 Ω 2.7 Ω 3.3 Ω 3.9 Ω 4.7 Ω 5.6 Ω 6.8 Ω 8.2 Ω 10.0 Ω

(Multiplied by any power of ten).

9

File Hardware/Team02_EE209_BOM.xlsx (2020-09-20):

ELECTENG 209: Analogue and Digital Design
Bill of Materials
Team Number: 02
Mobile Number 1: 0210341007 (Krithik Lekinwala)
Mobile Number 2: 0276082787 (Ruskin Swedlund)
Standard Part - Change QTY if Needed
Description | Through-Hole Part Number | QTY
5V linear regulator | LM78L05 | 1
DIP16 OpAmp | LM324 | 2
DIP8 OpAmp | LM358 | 0
Microcontroller | Xplained Mini 328PB | 1
BLE module | HM10 | 1
100V 300mA fast switching diode | 1N4148 | 1
50V 1A standard diode | 1N4007 | 2
Standard green LED | 703-0097 | 1
4.7V zener diode | BZX79-C4V7 | 4
35V 22uF electrolytic capacitors | EEU-FC1J220 | 1
35V 47uF electrolytic capacitors | EEU-FC1J470 | 1
IC base for LM324 | DIP16 Base | 1
IC base for LM358 | DIP8 Base | 0
Load connector | Banana sockets with soldered wires | 2
AC socket | 3.5mm power connector with soldered wires | 1
Male header for display | Male double row 16x2 header | 1
Male header for Xplained Mini | Single row male headers | 2
Female header for HM10 | Single row 6-pin female header | 1
4 digit 7-segment display | HDSP-5523 based display with 74HCN595 | 1
Toolkit | ECSE standard toolkit | 1
Breadboard | Full-size breadboard | 1
Single core wire - black | 0.5m length | 1
Single core wire - red | 0.5m length | 1
Single core wire - yellow | 0.5m length | 1
Single core wire - white | 0.5m length | 1
Emulator board | EE209 Emulator | 1
Resistors - E12 Series Values between 1 Ohm and 100 kOhm (ROYALOHM MF006 series)
Designators | Value | QTY
Ra | 56k | 1
Rb | 3k3 | 1
Rin | 33 | 1
RL | 100 | 1
R1 | 270 | 1
R9, R10 | 22k | 2
R11, R12 | 56k | 2
R13 | 1k5 | 1
R14, R15, R16 | 4k7 | 3
R17, R21 | 18k | 2
R18 | 13k | 1
R20 | 33k | 1
RP1, RP2, RP3, RP4 | 10k | 5
RP5 | 2k7 | 1
RP6 | 6k2 | 1
Rf1, Rf2 | 33k | 2
Ceramic Capcitors - E6 Series Values Between 100 pF and 1 uF (TDK FK28C0G or Murata RHEL81H)
Designators | Value | QTY
C1, C2, C3, C4, C5, C6, C7, C8 | 100n | 8
Cf1, Cf2 | 4n7 | 2
CP1 | 1u | 1
Film Capcitors - E6 Series Values Between 1 nF and 680 nF (Suntan TS05)
Designators | Value | QTY
Non-Standard Parts - If needed from ECSE Component Inventory
Description | Through-Hole Part Number | QTY

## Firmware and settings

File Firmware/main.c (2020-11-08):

/* Energy Monitor Main for ATmega328PB */

/* Local Includes */
#include "common.h"
#include "uart.h"
#include "adc.h"
#include "timer0.h"
#include "timer2.h"
#include "dsp.h"
#include "display.h"

/* AVR Includes */
#include <avr/io.h>
#include <avr/interrupt.h>


/* #define ENABLE_TESTING */
volatile unsigned enable_zc = 1;

int main()
{
#ifdef ENABLE_TESTING
	extern void test_function();
	test_function();
#endif /* ENABLE_TESTING */
	unsigned sampeled_voltage_current = 0;

	DDRB = 0xFF;

	/* Initalisation code */
	usart_init();
	adc_init();
	timer0_init();
	timer2_init();
	disp_init();
	voltage_zc_interrupt_init();

	/* Globally Enable Interrupts */
	sei();

	while (1) {
		if (!currently_sampling && !enable_zc) {
			if (sampeled_voltage_current) {
				adc2real_voltage();
				adc2real_current();
				/*for (int i = 0; i < RAW_ARRAY_SIZE; ++i) {
					print("%f \r\n", raw_currents[i]);
				}*/
				cubic_interpolate();
				calculate_power();
				calculate_energy();
				calculate_pk_current();
				calculate_rms_voltage();
			
				/* print once per second */
				if (print_uart) {	
					print("%f V(RMS)\r\n", rms_voltage);
					print("%f A(PK)\r\n", pk_current);
					print("%f W\r\n", power);
					print("%f Wmin\r\n", energy);
					print("\r\n");
					print_uart = 0;
				}

				sampeled_voltage_current = 0;
				enable_zc = 1;
			} else { /* We still need to sample current */
				sampeled_voltage_current = enable_zc = 1;
			}
		}
		if(change_display){
			disp_next_value();
		}
	}

	return 0;
}

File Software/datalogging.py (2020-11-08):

#!./env/bin/python
# The Above She-Bang ensures we are using the virtualenv

# This file uploads the data to the server from Bluetooth / UART / other sources

import os
import signal
import json
import requests # For talking to the webserver
import serial # For uart


run_input_loop = True
# URL to upload data to
#	http://127.0.0.1:5000/add/records (for testing)
#	https://ee209t02.herokuapp.com/add/records
request_url = "https://ee209t02.herokuapp.com/add/records"

def sigint_handle(signalnum, flag):
	global run_input_loop
	run_input_loop = False

def run():
	if os.name == "posix":
		port_name = input("Enter device to open (e.g. /dev/ttyUSB0): ")
	elif os.name == "nt":
		port_name = input("Enter device to open (e.g. 'COM0'): ")
	else:
		port_name = input("Enter device to open: ")

	try:
		# Open named port at ?9600 baud,8N1?, one second timeout:
		port = serial.Serial(port_name, 9600, timeout=1)
	except:
		print("Failed to open port " + port_name)
		exit()

	data = []
	print("Capturing Data from UART... Press CTRL + C To stop capture")

	signal.signal(signal.SIGINT, sigint_handle)
	while run_input_loop:
		# This is the expected output order of uart
		voltage = None
		current = None
		power = None
		energy = None

		while not voltage or not current or not power or not energy:
			try:
				line = port.readline().strip().decode()
			except serial.SerialTimeoutException:
				print("Reading Line From UART Timed Out. Trying Again...")
				continue

			if "V(RMS)" in line:
				voltage = float(line.split(' ')[0])
			elif "A(PK)" in line:
				current = float(line.split(' ')[0])
			elif "Wmin" in line:
				energy = float(line.split(' ')[0])
			elif "W" in line:
				power = float(line.split(' ')[0])
			
		if voltage and current and power and energy:
			data.append([voltage, current, power, energy])
			print("Apending")


	print("Finished Collecting Data - Uploading Now ... ")
	print(data)	
	status = requests.post(request_url, json=data)
	while status.status_code != 200:
		status = requests.post(request_url, json=data)
		print(status)
		print("Upload Failed, Trying Again!")
	print("Data Upload Complete (%d seconds worth of data)" % len(data))

	port.close()

if __name__ == "__main__":
	run()

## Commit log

2020-08-16 Finished Current and Voltage sensor section of component doc.
2020-08-19 Added bluetooth UART specs to project documentation
2020-08-20 Updated components file with Schmit Trigger for zero voltage crossing
2020-08-21 Added a Python script to generate an AtmelStudio Soultion/Project from existing sources. Fixed (printing) Typo in Makefile Generated Atmel Studio Soultion Files using New Python Script Added .xml fil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
2020-08-22 Implemented print_array_intergers.
    Retroactively defined ascii_convert and extract_digits as static functions.
2020-08-22 Added new files for ADC. Updated Makefile to build ADC files, Regenerated Atmel Studio Project Files.
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2020-08-24 Added complete hardware LTspice schematic
    Some component values are incorrect from documentation. .tex file modified.
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2020-08-25 Fxied Bug With UART Implimentation, Fixed bug in print() function, Fixed bug in Makefile, Modified Testing Code
    [main.c, test.c, uart.c]
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2020-08-26 Added terminal_print and fixed print_interger
    [main.c, uart.c]
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2020-08-26 Added printing string functionality to print() function. Added Test Case for printing string.
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2020-08-26 Fixed unsued paramater warnings
    [main.c]
2020-08-28 Increased peaks of condiitoning circuit out puts by ~200mV
    Current sensor:
    Condition Circuit:
    - R1 -> 22k, R2 -> 56k, gain = 2.54
    Voltage snersor:
    Divider Circuit:
    - R1 -> 56k, R2 -> 3.3k (2.4Vpp output)
    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
2020-08-30 Revert "LtSpice Sim, reverted to old R values." opAmp filter removed.
    This reverts commit 2d73d053528f5ec55da6823074e2d978bb067047.
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2020-08-30 Fixed terminal_print() to use parameters instead of macro
    [main.c]
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2020-09-10 Completed Schematic and added Component Library
    [PCB_Schematic.SchDoc]
2020-09-12 Added decoupling capacitors (0.1uF) to reduce noise, changed capacitors to single layer ceramic caps. Added electrolytic capacitors to regulator
    [PCB_Schematic.SchDoc]
2020-09-13 Update PCB_Schematic.SchDoc
    - Renamed BLE nets.
    - Added TX test point.
    - Fixed Vzc.
    [PCB_Schematic.SchDoc]
2020-09-15 Added an SMT design (if we want to pursue that) and change voltage divider R vals
    [PCB_Schematic SMT.SchDoc, PCB_Schematic.SchDoc]
2020-09-16 Uploaded completed PCB layout and modified TH Schemaic file..
    - OpAmp allocation reallocated for easier routing.
    [PCB_Schematic.SchDoc]
2020-09-17 Added project file, make sure to open this file if you need to make edits to Schem/Layout
    [PCB_EnergyMonitor SMT.SchDoc, PCB_EnergyMonitor.PrjPcb, PCB_EnergyMonitor.SchDoc]
2020-09-17 Presentation edits
    [PCB_EnergyMonitor.SchDoc]
2020-09-17 Added BOM
    [Team02_EE209_BOM.xlsx]
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2020-09-17 Updated nets, added peak detector circuit into PCB schematic
    [PCB_EnergyMonitor.PrjPcb, PCB_EnergyMonitor.SchDoc, Team02_EE209_BOM.xlsx]
2020-09-17 Aligned to grid
    [PCB_EnergyMonitor.PrjPcb, PCB_EnergyMonitor.SchDoc]
2020-09-17 Peak detector connected to PC5
    [PCB_EnergyMonitor.SchDoc]
2020-09-20 Updated cf1 and cf2 to 4.7nF
    [PCB_EnergyMonitor.PrjPcb, PCB_EnergyMonitor.SchDoc, Team02_EE209_BOM.xlsx]
2020-09-23 electrolyte capacitor 27u to 22u
    [PCB_EnergyMonitor.PrjPcb, PCB_EnergyMonitor.SchDoc]
2020-09-23 Updated Slides (Added voltage input range before/after for ADC input)
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2020-09-29 Adde annotated PCB image. Script updated with latest slides.
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2020-10-03 Added timer0 init and adc sampling ISR triggered every 1ms
2020-10-06 ADC samples @ 1 ms interval, alternating voltage and current - takes 10 samples of each, overwrites previous samples. samples are printed (along with sample time) to uart. Dummy function for reversin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
    [adc.c, dsp.c, dsp.h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]
2020-10-06 Fixed missnumebring of ADC channels
    [adc.c]
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2020-10-08 Added functions to reverse gain of ADC voltage and current input
    [dsp.c, dsp.h]
2020-10-08 Changed reverse gain function to snake_case
    [adc.c, dsp.c, dsp.h]
2020-10-08 Implemented voltage_zc ISR. Period calc not yet implemented.
2020-10-10 Updated reverse gain formulas
    [dsp.c]
2020-10-10 Fixed reverse_current_gain()'s variable name.
    [dsp.c]
2020-10-10 Prepearation for free running timer0. Need to discuss with team.
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2020-10-11 Implemented Vzc ISR and period calculation. Had to restructure timer0.
    However, the consequences of my implementation is that we cannot do signal processing as we sample. As the lag will desync the time, the measured cycle and its voltage values.
2020-10-11 Added printing negative float numbers to UART implimentation
2020-10-11 Restructed location of global Voltage & Current arrays into dsp.c
2020-10-11 Modified reverse_*_gian functions to work with new arrays
    [adc.c, dsp.c, dsp.h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]
2020-10-12 Updated Proteus circuit values to Hardware values at 7.5VA
2020-10-12 Updated correct gain for reverse_voltage_gain()
    [dsp.c]
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2020-10-12 Cleaned up code in adc ISR to a sampling_init() function.
2020-10-13 Refactored adc and singnal proecssing code to remove signal_start flag
2020-10-13 Moved calculations out of ADC Interrupt; Moved sampling control to zero crossing. Many other improvments
2020-10-13 Fixed reverse gain expressions
    [dsp.c, main.c]
2020-10-13 Added schematic images to PCB section in report
2020-10-14 Shifted around images ( Need to add updated schematic excluding peak detector)
2020-10-14 ADC sampling and reverse voltage gains fixed
    [dsp.c, dsp.h, main.c]
2020-10-14 Interpolation working + sampling 20 Voltage then 20 Current samples
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2020-10-14 Added Disp_Init, Disp_Set, macros to disable/enable displays and turn on/off the shift register
    Changed the static type variable 'sevenSegMapping' from type char to type uint8_t for bit shifting. Added arrays to hold the displays (Ds1, Ds2, Ds3, Ds4) and to hold the place values of a float inpu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
    the Disp_Set function now utilises our UART extract functions (extract_digits, extractTenths, extractHundredths) to write these extracted values into the placeValues array which will then be shifted 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
    Implemented macros for easy use instead of using an entire function.
2020-10-14 Implimented integration and inital power calculation 3.9% error :(
    [dsp.c, dsp.h, main.c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]
2020-10-14 Improved interpolation function (better interpolation for first and last points). Accuracy incressed to 1.447 % Error .
    [display.c, dsp.c, dsp.h]
2020-10-15 Added force sample to get 20th ADC sample, improved interpolation of last 2 points
2020-10-15 Chnaged Zero Crossing Thershold in proteus file to correct one
    [dsp.c]
2020-10-16 Added (Blank) Functions to calcualte RMS Voltage, Peak Current, and Energy
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2020-10-16 usart_print_float() no longer prints leading zero if hundreds column is empty
    [uart.c]
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2020-10-20 Completed flowchart implementation for report, added small paragraphs on special implementations for software
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2020-10-20 Fixed inlcude guards in timer2.h
    [dsp.c, main.c]
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2020-10-22 Completed Design Validation of ADC, Timers, Display, and shift register. Also changed display update from 40ms -> 10ms to reduce flickering.
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2020-10-24 Properly turned timer2 to change display at 1s 1s
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2020-10-24 Completed report and added Excel spreadsheet containing accuracy values
    [Graphs for Report.xlsx]
2020-10-24 Fixed graph, edited formatting
    [Graphs for Report.xlsx]
2020-10-24 Updated PCB schematic with values, fixed a connection. Removed report template temp files
    [PCB_EnergyMonitor.SchDoc]
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2020-10-25 Changed introduction
    [Graphs for Report.xlsx]
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2020-10-26 addec voltage and power correction MACROS
    [dsp.c]
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2020-10-26 Created new accuracy graphs
    [Graphs for Report.xlsx]
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2020-10-26 Added more code to prevent caching
    [app.py]
2020-10-26 Fixed indentation in app.py
    [app.py]
2020-11-02 Updated LTspice regulator resistor from 13K to hardware value of 12K Added ifdefs for reverse gain for xplainedmini board
    [datalogging.py, dsp.c]
2020-11-04 Fixed flowchart link.
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2020-11-05 Added graphs to show peak accuracy without peak detector, added slide for project management
    [Graphs for Report.xlsx]
2020-11-06 Dirty PCB push: Defined HARDWARE_BUILD. Removed gain = 0. SET REF0. Changed correct prescalar for adc.
    [adc.c, dsp.c]
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2020-11-08 Updated PBC firmware correction functions
    [dsp.c, main.c]
2020-11-08 Fixed physical display flickering
    [timer2.c]
2020-11-08 Added ifdef for hardware values and correction factor.
    [dsp.c, timer2.c]
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2020-11-08 Correct comment for timer2
    [timer2.c]
2020-11-08 Fixed period, delta x for trp intergration
    [dsp.c]
2020-11-08 fixed datalogging script bug, fixed energy calculation
    [datalogging.py, dsp.c]
